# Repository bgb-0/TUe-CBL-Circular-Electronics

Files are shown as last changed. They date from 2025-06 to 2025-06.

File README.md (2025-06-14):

# :recycle: Prototype Audio PCB for TU/e 4CBLW00-11 course
This repository contains the PCB design files (KiCad 9), schematic, and 3D model image
for a prototype modular bluetooth audio board, based on te ESP32-Mini-1 module.
This is a prototype PCB designed for a modular bluetooth speaker, for the Multidisciplinary CBL (4CBLW00) course of year 2024/2025, made possible with help from Darije Caic.
<div align="center">
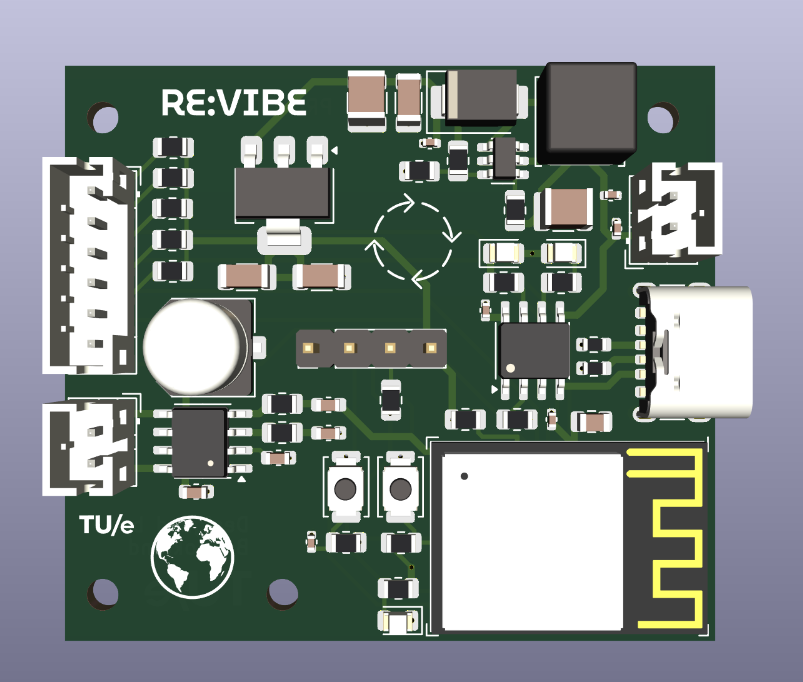
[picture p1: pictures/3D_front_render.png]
A 3D render of the front side of the PCB
  
</div>

## :round_pushpin: Features
- ESP32-MINI-1 module for bluetooth connectivity and low-power
- Detacheable speaker and battery
- USB-C power delivery
- Small form factor (45 x 40 mm)
## :card_file_box: Contents
- PCB design files: The KiCad project files for the PCB design.
- Schematic: The circuit diagram of the design.
- 3D model image: A preview image of the 3D model of the board.
## :pencil2: Schematic 
<div align="center">
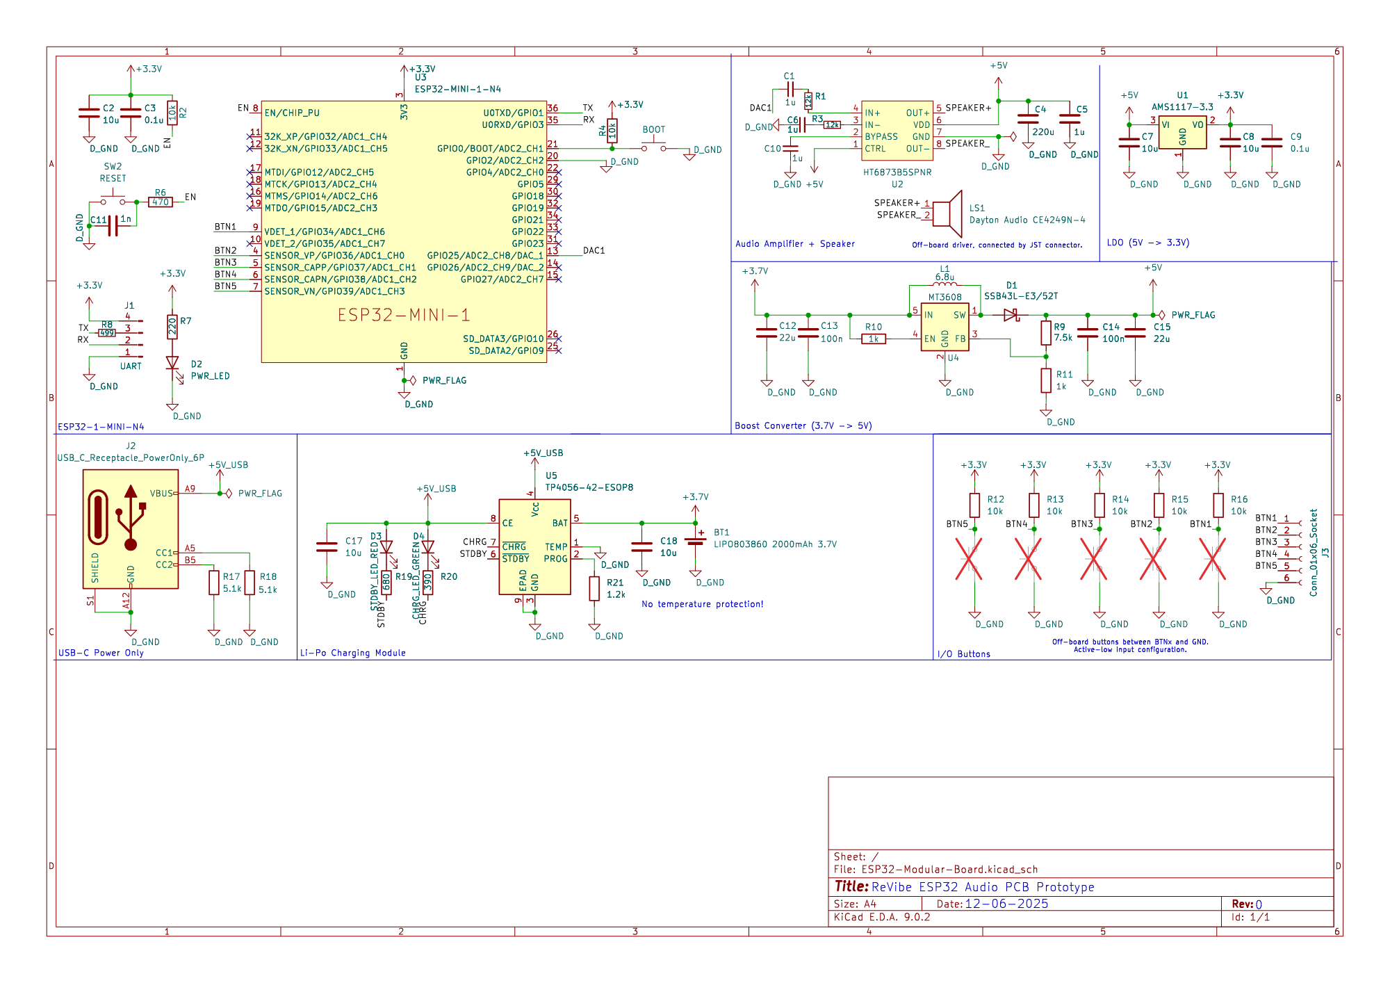
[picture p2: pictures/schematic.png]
A picture of the schematic of the PCB
  
</div>

## :triangular_ruler: Lay-out
<div align="center">
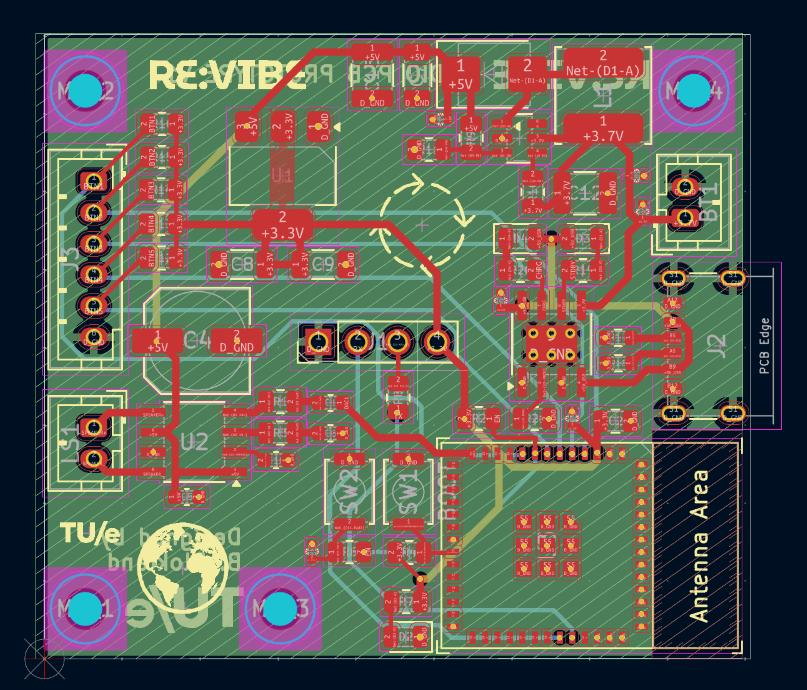
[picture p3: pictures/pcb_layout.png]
A picture of the physical lay-out of the PCB
  
</div>

## :hammer_and_wrench: License
This hardware design is licensed under the CERN Open Hardware Licence Version 2
 – Permissive, as approved by the Technische Universiteit Eindhoven (TU/e).

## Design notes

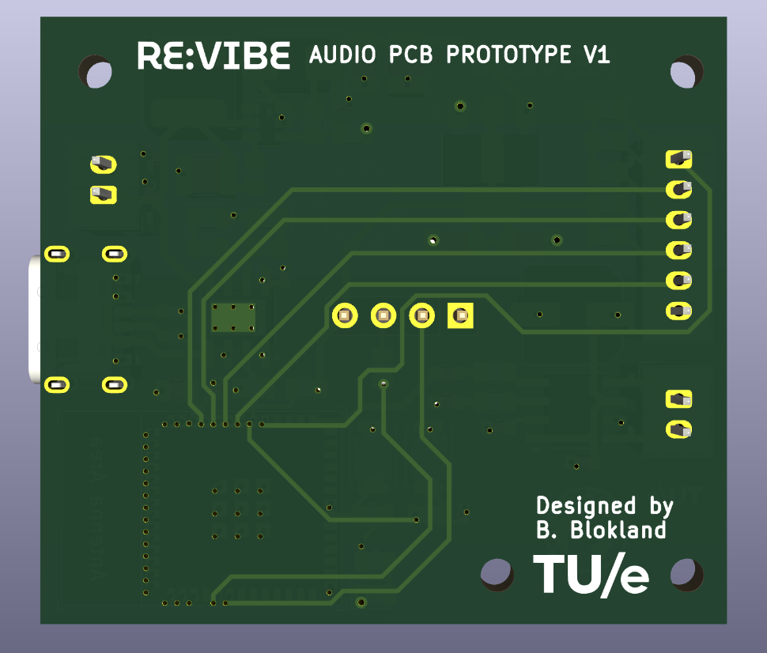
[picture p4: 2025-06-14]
pictures/3D_back_render.png

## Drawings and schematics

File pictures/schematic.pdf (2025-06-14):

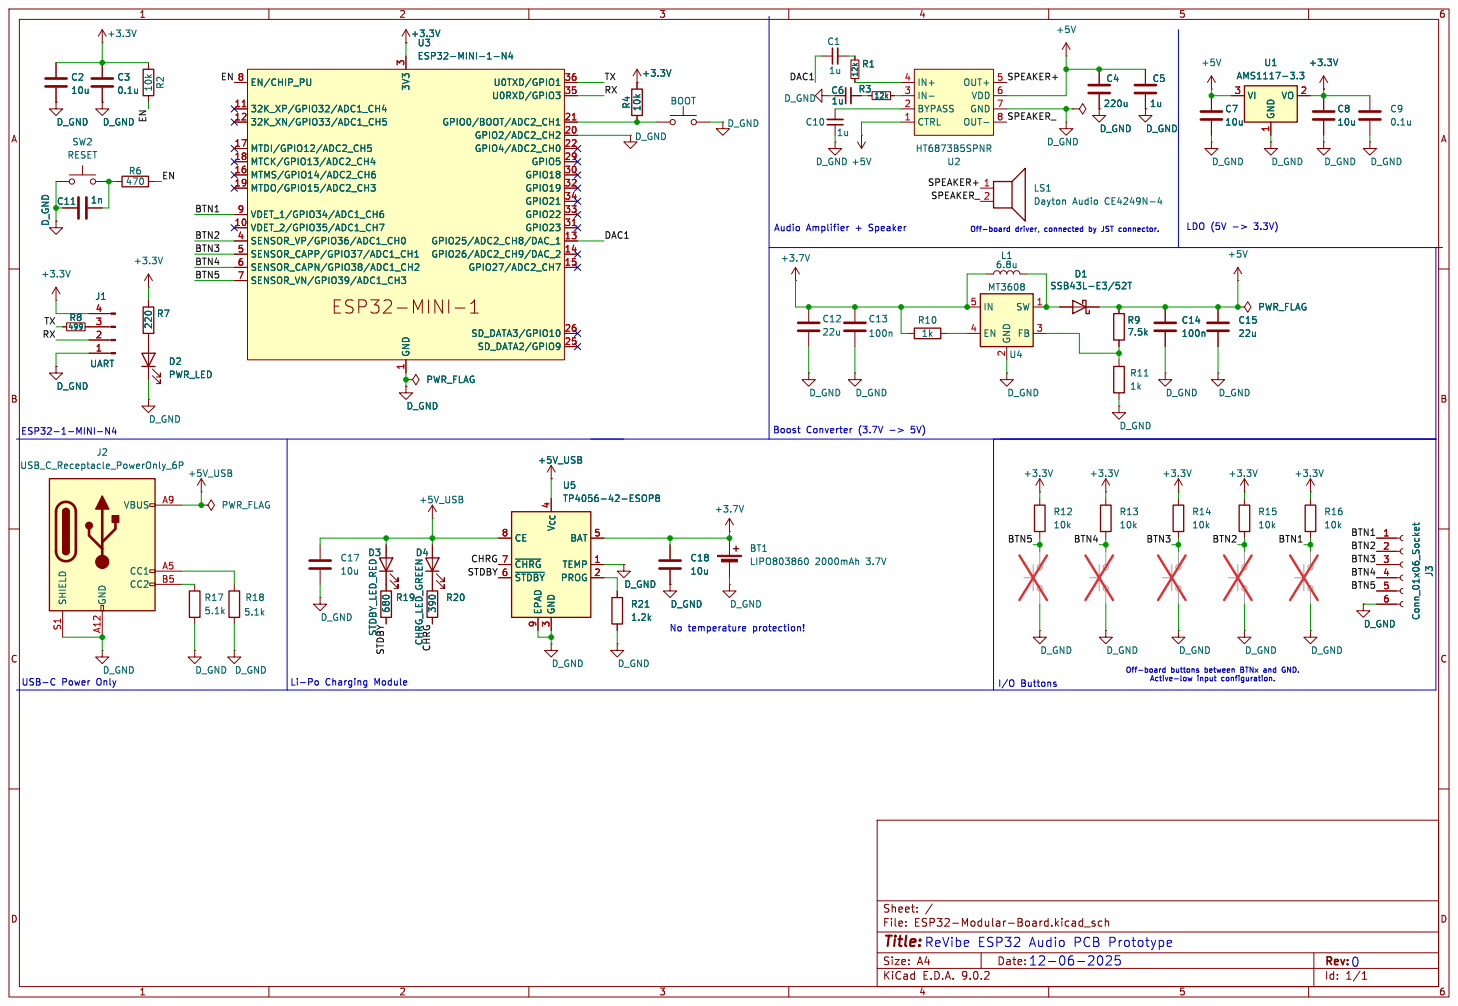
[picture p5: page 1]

Id: 1/1 Title: File: ESP32-Modular-Board.kicad_sch Sheet: /

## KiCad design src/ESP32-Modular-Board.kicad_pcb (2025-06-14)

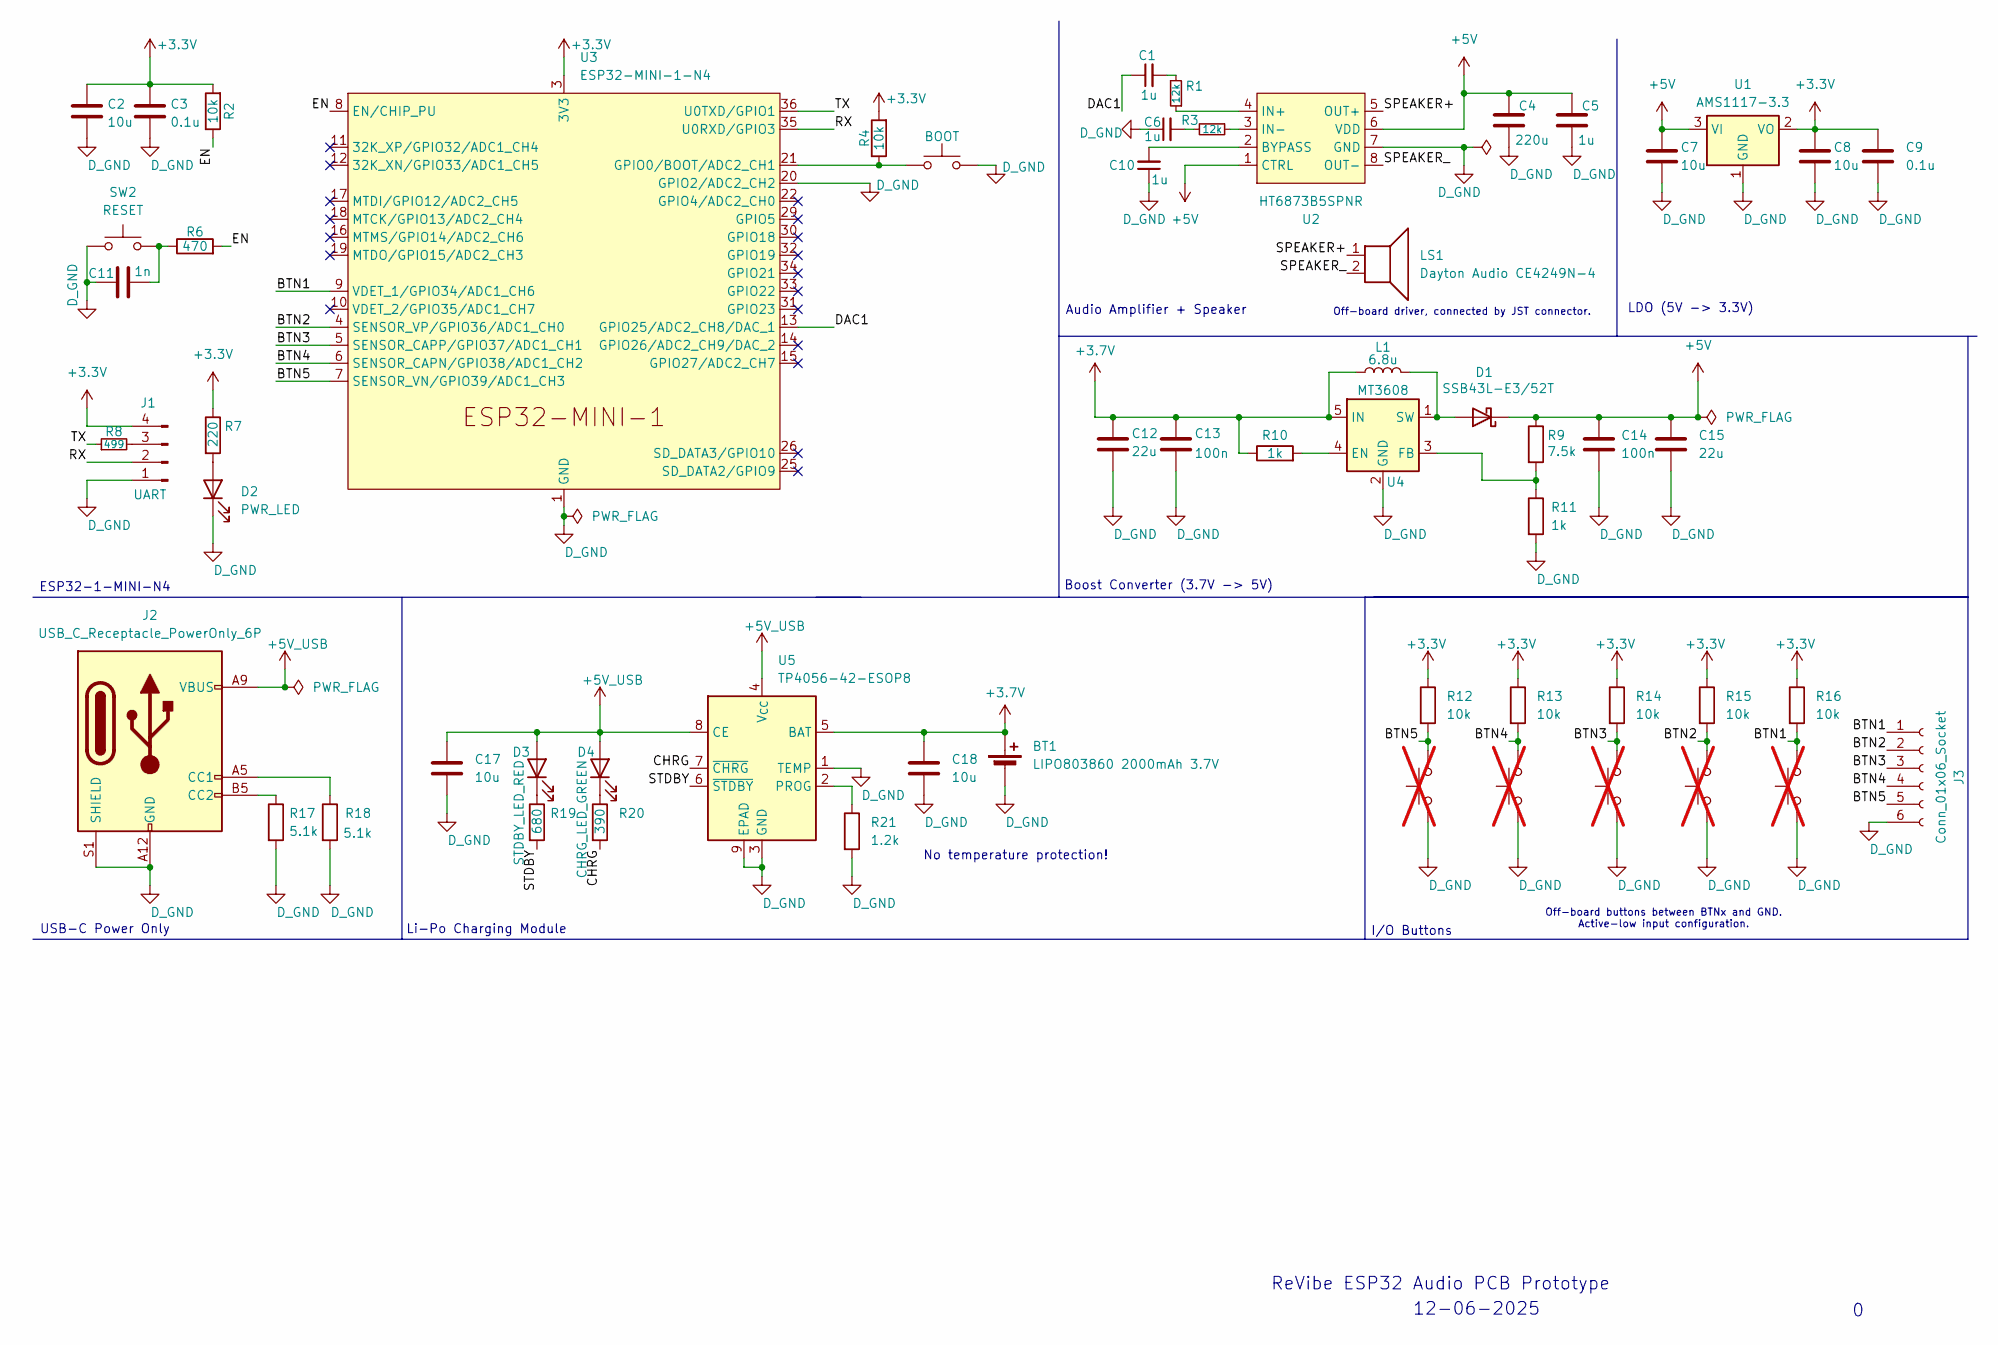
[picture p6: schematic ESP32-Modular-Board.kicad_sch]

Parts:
BT1: LIPO803860 2000mAh 3.7V; JST_PH_B2B-PH-K_1x02_P2.00mm_Vertical
C1, C5, C6, C10: 1u; C_0603_1608Metric
C2: 10u; C_0805_2012Metric
C3: 0.1u; C_0402_1005Metric
C4: 220u; C_Elec_6.3x5.8
C7, C8: 10u; C_1206_3216Metric
C9: 0.1u; C_1206_3216Metric
C11: 1n; C_0402_1005Metric
C12, C15: 22u; C_1210_3225Metric
C13, C14: 100n; C_0402_1005Metric
C17, C18: 10u; C_0402_1005Metric
D1: SSB43L-E3/52T; D_SMB
D2: PWR_LED; LED_0805_2012Metric
D3: STDBY_LED_RED; LED_0805_2012Metric
D4: CHRG_LED_GREEN; LED_0805_2012Metric
J1: UART; PinHeader_1x04_P2.54mm_Vertical
J2: USB_C_Receptacle_PowerOnly_6P; USB_C_Receptacle_GCT_USB4125-xx-x-0190_6P_TopMnt_Horizontal
J3: Conn_01x06_Socket; JST_PH_B6B-PH-K_1x06_P2.00mm_Vertical
L1: 6.8u; L_TDK_VLS6045EX_VLS6045AF
LS1: Dayton Audio CE4249N-4; JST_PH_B2B-PH-K_1x02_P2.00mm_Vertical
R1, R3: 12k; R_0805_2012Metric
R2, R4, R12, R13, R14, R15, R16: 10k; R_0805_2012Metric
R6: 470; R_0805_2012Metric
R7: 220; R_0805_2012Metric
R8: 499; R_0805_2012Metric
R9: 7.5k; R_0805_2012Metric
R10, R11: 1k; R_0805_2012Metric
R17, R18: 5.1k; R_0603_1608Metric
R19: 680; R_0805_2012Metric
R20: 390; R_0805_2012Metric
R21: 1.2k; R_0805_2012Metric
SW1: BOOT; SW_Push_SPST_NO_Alps_SKRK
SW2: RESET; SW_Push_SPST_NO_Alps_SKRK
SW3, SW4, SW5, SW6, SW7: SW_Push; not fitted
U1: AMS1117-3.3; SOT-223-3_TabPin2
U2: HT6873B5SPNR; SOP-8_3.9x4.9mm_P1.27mm
U3: ESP32-MINI-1-N4; ESP32-MINI-1
U4: MT3608; SOT-23-6
U5: TP4056-42-ESOP8; SOIC-8-1EP_3.9x4.9mm_P1.27mm_EP2.41x3.3mm_ThermalVias

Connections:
+3.3V: C2.1, C3.1, C8.1, C9.1, J1.4, R2.2, R4.2, R7.1, R12.1, R13.1, R14.1, R15.1, R16.1, U1.2 (VO), U3.3 (3V3)
+3.7V: BT1.1 (+), C12.1, C13.1, C18.1, L1.1, R10.1, U4.5 (IN), U5.5 (BAT)
+5V: C4.1, C5.1, C7.1, C14.1, C15.1, D1.1 (K), R9.1, U1.3 (VI), U2.1 (CTRL), U2.6 (VDD)
+5V_USB: C17.1, D3.2 (A), D4.2 (A), J2.A9 (VBUS), J2.B9 (VBUS), U5.4 (V_{CC}), U5.8 (CE)
/BTN1: J3.1, R16.2, SW7.2, U3.9 (VDET_1/GPIO34/ADC1_CH6)
/BTN2: J3.2, R15.2, SW6.2, U3.4 (SENSOR_VP/GPIO36/ADC1_CH0)
/BTN3: J3.3, R14.2, SW5.2, U3.5 (SENSOR_CAPP/GPIO37/ADC1_CH1)
/BTN4: J3.4, R13.2, SW4.2, U3.6 (SENSOR_CAPN/GPIO38/ADC1_CH2)
/BTN5: J3.5, R12.2, SW3.2, U3.7 (SENSOR_VN/GPIO39/ADC1_CH3)
/CHRG: R20.2, U5.7 (~CHRG)
/DAC1: C1.1, U3.13 (GPIO25/ADC2_CH8/DAC_1)
/EN: R2.1, R6.2, U3.8 (EN/CHIP_PU)
/RX: J1.2, U3.35 (U0RXD/GPIO3)
/SPEAKER+: LS1.1, U2.5 (OUT+)
/SPEAKER_: LS1.2, U2.8 (OUT-)
/STDBY: R19.2, U5.6 (~STDBY)
/TX: R8.1, U3.36 (U0TXD/GPIO1)
D_GND: BT1.2 (-), C2.2, C3.2, C4.2, C5.2, C6.1, C7.2, C8.2, C9.2, C10.1, C11.1, C12.2, C13.2, C14.2, C15.2, C17.2, C18.2, D2.1 (K), J1.1, J2.A12 (GND), J2.B12 (GND), J2.S1 (SHIELD), J3.6, R11.2, R17.2, R18.2, R21.2, SW1.2, SW2.1, SW3.1, SW4.1, SW5.1, SW6.1, SW7.1, U1.1 (GND), U2.7 (GND), U3.1 (GND), U3.2 (GND), U3.20 (GPIO2/ADC2_CH2), U3.27 (GND), U3.38 (GND), U3.39 (GND), U3.40 (GND), U3.41 (GND), U3.42 (GND), U3.43 (GND), U3.44 (GND), U3.45 (GND), U3.46 (GND), U3.47 (GND), U3.48 (GND), U3.49 (GND), U3.50 (GND), U3.51 (GND), U3.52 (GND), U3.53 (GND), U3.54 (GND), U3.55 (GND), U4.2 (GND), U5.1 (TEMP), U5.3 (GND), U5.9 (EPAD)
unnamed: C1.2, R1.2
unnamed: C6.2, R3.2
unnamed: C11.2, R6.1, SW2.2
unnamed: D1.2 (A), L1.2, U4.1 (SW)
unnamed: D2.2 (A), R7.2
unnamed: D3.1 (K), R19.1
unnamed: D4.1 (K), R20.1
unnamed: J1.3, R8.2
unnamed: J2.A5 (CC1), R18.1
unnamed: J2.B5 (CC2), R17.1
unnamed: C10.2, U2.2 (BYPASS)
unnamed: R1.1, U2.4 (IN+)
unnamed: R3.1, U2.3 (IN-)
unnamed: R4.1, SW1.1, U3.21 (GPIO0/BOOT/ADC2_CH1)
unnamed: R10.2, U4.4 (EN)
unnamed: R9.2, R11.1, U4.3 (FB)
unnamed: R21.1, U5.2 (PROG)

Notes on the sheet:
Boost Converter (3.7V -> 5V)
Li-Po Charging Module
Off-board buttons between BTNx and GND. Active-low input configuration.
No temperature protection!
12-06-2025
ReVibe ESP32 Audio PCB Prototype
USB-C Power Only
LDO (5V -> 3.3V)
ESP32-1-MINI-N4
Off-board driver, connected by JST connector.
Audio Amplifier + Speaker
I/O Buttons

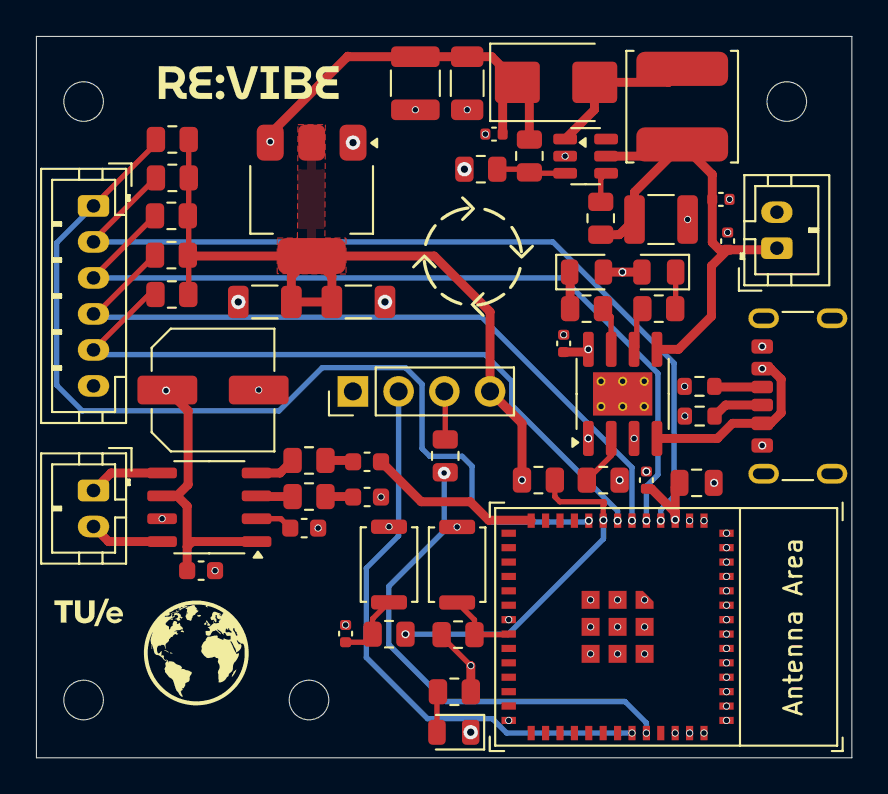
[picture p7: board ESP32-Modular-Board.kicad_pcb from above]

Board: 4 copper layers, 45.3 x 40.1 mm, 58 parts (0 on the bottom side), 35 nets.

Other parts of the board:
M2_1, M2_2, M2_3, M2_4: MountingHole_2.2mm_M2

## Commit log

2025-06-14 Initial PCB design for TU/e 2024/2025 CBL Circular Electronics
    [ESP32-Modular-Board.kicad_pcb, ESP32-Modular-Board.kicad_sch]
2025-06-14 Reorganized file structure
    [ESP32-Modular-Board.kicad_pcb, ESP32-Modular-Board.kicad_sch]
2025-06-14 Added pictures
    [ESP32-Modular-Board.kicad_pcb, ESP32-Modular-Board.kicad_sch]
2025-06-14 Add picture of schematic
